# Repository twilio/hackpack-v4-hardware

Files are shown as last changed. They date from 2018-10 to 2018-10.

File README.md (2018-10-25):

# Hackpack v4 Hardware Collateral
This repo contains all of the hardware collateral you need to create a device functionally equivalent to the [Hackpack v4](https://hackpack.cc/) from [Twilio's SIGNAL 2018](https://signal.twilio.com/) Conference.

<p align="center">
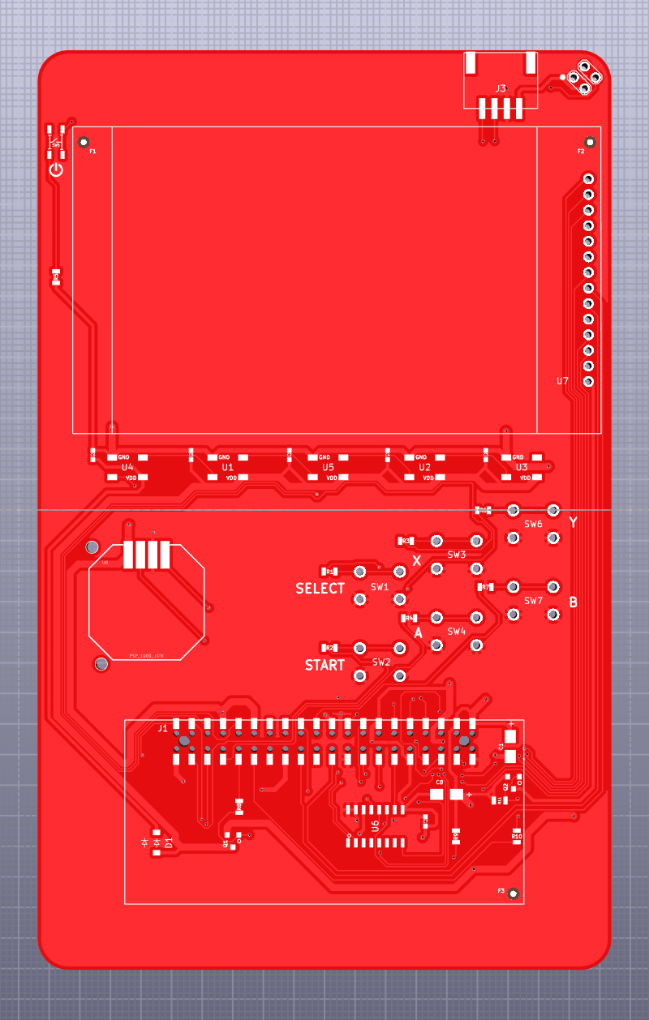
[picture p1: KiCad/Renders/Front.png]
Hackpack v4
  
</p>

See also our [blog post](https://www.twilio.com/blog/open-source-hardware-badge-hackpack-v4) announcing this repository.

## Hardware Collateral

Everything you need to build a badge PCB can be found in the `KiCad` folder. The Hackpack v4 was designed using KiCad major version 5. [Download a copy here](http://kicad-pcb.org/download/).

You'll also need to purchase a Raspberry Pi Zero W and a 8GB or larger MicroSD card to use the board.

### Don't want to use KiCad?

You can find pre-generated Gerbers in the `KiCad/Gerbers` directory. Use them at your PCB house of choice to manufacture a board.

We've also included the bill of materials and schematic in generic formats.

## Firmware

You can find firmware either [through our repository](https://github.com/twilio/hackpack-v4-firmware/) (start with a vanilla Raspbian installation) or pre-imaged on the [Hackpack v4](https://hackpack.cc/) site.

## Special Assembly Instructions

The Bill of Materials can be found in the `KiCad` directory. Some parts cannot be found at the normal supply sources and are best sourced from Amazon. 

The SMD Grove header was impossible to find in the US at the time this repo was released. Use a through hole Grove header and bend the pins with pliers for an excellent substitute.

The Amazon ILI9341 screen linked in the special assembly instructions has an inverted touchscreen to the one we used at the show. To fix the touchscreen driver you'll need to set flags:

```
echo "100" > /home/pi/.ili9341_touch.conf
sudo reboot
```

## License

Hardware collateral is licensed under [Solderpads 2.0](http://solderpad.org/licenses/SHL-2.0/), a hardware wrapper for the Apache 2.0 license. Please find a copy of both licenses in this repository.

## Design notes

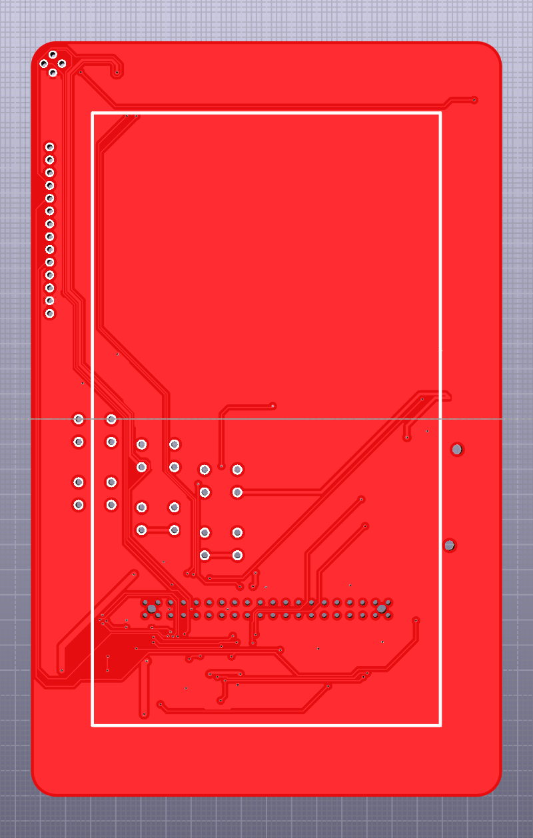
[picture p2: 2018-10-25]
KiCad/Renders/Back.png

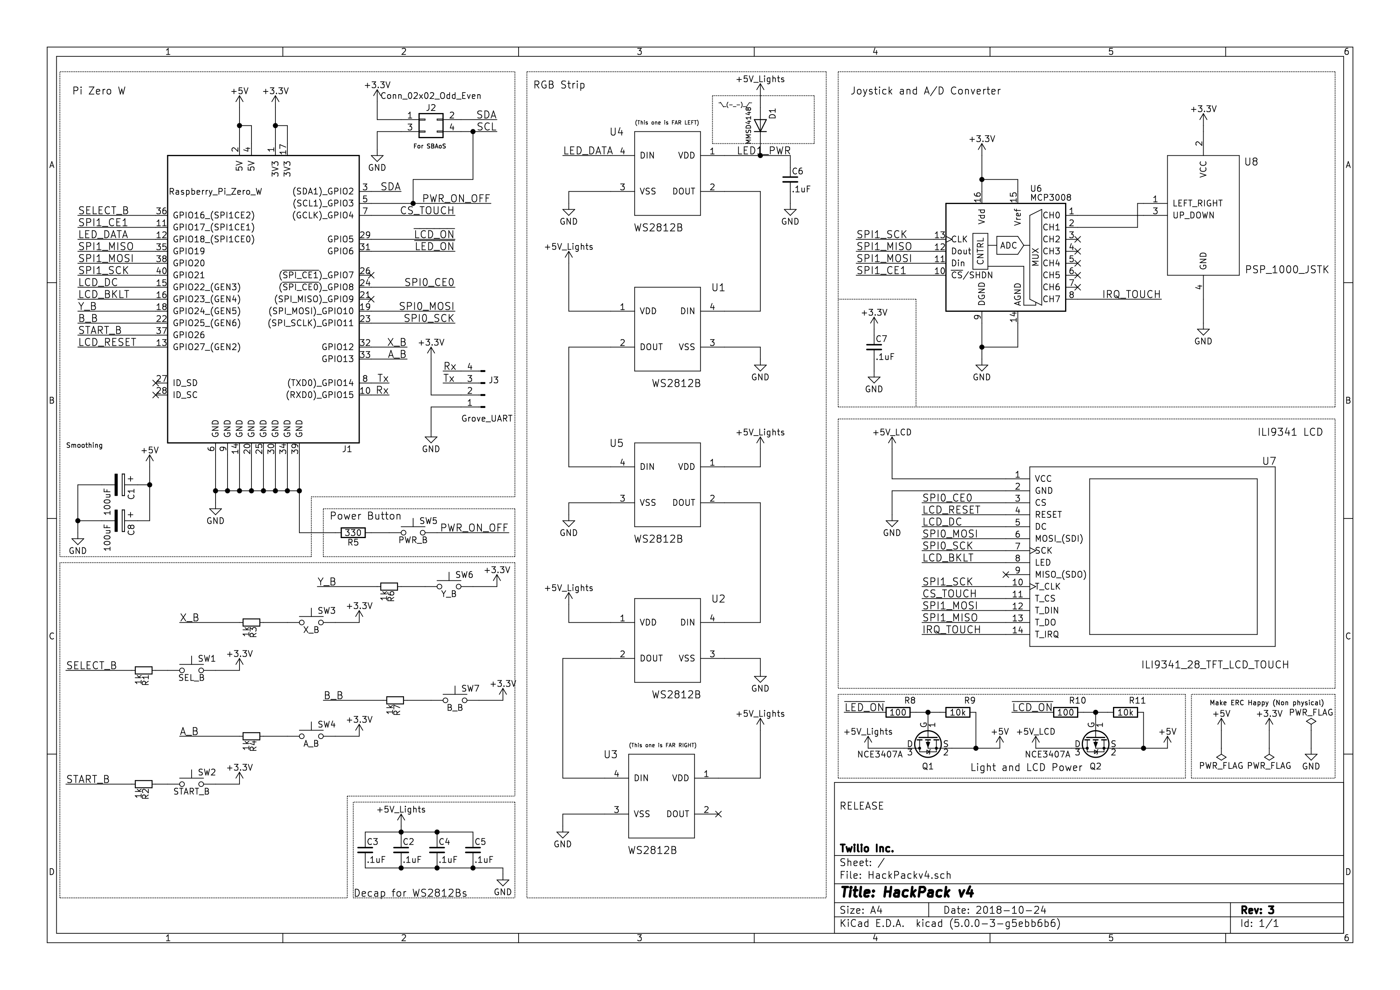
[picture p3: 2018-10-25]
KiCad/HackPackv4.sch.png

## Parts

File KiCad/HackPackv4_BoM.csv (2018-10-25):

Component | Description | Part | References | Value | Footprint | Quantity Per PCB | Datasheet | MFP | MFN | Characteristics | Can_Substitute | Notes | Package
1 | CAP CER 0.1UF 50V X7R 0603 | C_Small | C2 C3 C4 C5 C6 C7 | .1uF | C_0603 | 6 | https://www.mouser.com/datasheet/2/281/murata_03122018_GCM_Series-1310150.pdf | GCM188R71H104KA57D | MURATA | 0603 100nF-50V-10%-X7R | Y
2 | SMD CAP Tantalum 100uF-10V | CP | C1 C8 | 100uF | CP_Tantalum_Case-B_EIA-3528-21_Wave | 2 | https://www.mouser.com/datasheet/2/40/f93-776559.pdf | F931A107KBA | AVX | 100uF 10V 20% | Y | 2x for Smoothing 5V
3 | SMD Diode Switching 100V-200mA | D | D1 | MMSD4148 | D_SOD-123 | 1 | https://www.onsemi.com/pub/Collateral/MMSD4148T1-D.PDF | MMSD4148T3G | ON Semiconductor | MUST DROP >= .3 Forward Voltage!! SMD Diode Switching 100V-200mA | N | To drop voltage for the first LED to meet the 70% spec.
4 | NO NOT POPULATE | Conn_02x02_Odd_Even | J2 | Conn_02x02_Odd_Even | Pin_Header_Straight_2x02_Pitch2.54mm | 1 | NONE | DNP | DNP | NO NOT POPULATE | N | NO NOT POPULATE | NO NOT POPULATE
5 | Grove UART Header - Solder bent pins onto pads | Conn_01x04_Male | J3 | Grove_UART | Grove_Taifeng_1125R-SMT-4P | 1 | https://www.digikey.com/product-detail/en/seeed-technology-co-ltd/110990037/1597-1083-ND/5482561 | Buy on Digikey and Modify | -- |  | N | Bend pins & solder sideways
6 | Surface mount low profile header 40 pin 2 row | Raspberry_Pi_Zero_W | J1 | Raspberry_Pi_Zero_W | M20-7812045 | 1 | https://cdn.harwin.com/pdfs/M20-781.pdf | HLE-120-02-G-DV-A | Samtec | 40 Pin 2x20 2.54mm pitch SMD. | Y | WAIT ON SUBSTITUTE FROM ERIN & TWILIO
7 | MOSFET P-CH 30V 4.3A SOT23 | NCE3407A | Q1 Q2 | NCE3407A | SOT-23 | 2 | http://aosmd.com/res/data_sheets/AO3407A.pdf | AO3407A | Alpha & Omega Semiconductor | VGS th < -3, 10+V, 500mA+ | Y | Turn on LEDs, Screen
8 | SMD RES 100R-5%-1/8W | R | R8 R10 | 100 | R_0805 | 2 | http://www.yageo.com/documents/recent/PYu-RC_Group_51_RoHS_L_9.pdf | RC0805JR-07100RL | Yageo | 100R 5% 1/8W 0805 | Y | MOSFET Gate Input Protection
9 | SMD RES 10K-1%-1/8W;0805 | R | R9 R11 | 10k | R_0805 | 2 | http://www.yageo.com/documents/recent/PYu-RC_Group_51_RoHS_L_9.pdf | RC0805FR-0710KL | Yageo | 10K 1% or 5% 1/8W | Y | MOSFET Gate Pullup
10 | SMD RES 1K-5%-1/8W;0805 | R_Small | R1 R2 R3 R4 R6 R7 | 1k | R_0805 | 6 | http://www.yageo.com/documents/recent/PYu-RC_Group_51_RoHS_L_9.pdf | RC0805JR-071KL | Yageo | 1K 5% 1/8W | Y
11 | SMD RES 330R-1%-1/8W;0805 | R | R5 | 330 | R_0805 | 1 | http://www.yageo.com/documents/recent/PYu-RC_Group_51_RoHS_L_9.pdf | RC0805FR-07330RL | Yageo | 0805 5% or 1% 330R 1/8W | Y | Protection on button/pulldown
12 | DIP Button;SPST;160gf | SW_Push | SW4 | A_B | TS-1109_6.2mm_Push | 1 | https://www.ctscorp.com/wp-content/uploads/222A.pdf | 222ADVBA | CTS Electrocomponents |  | N | Used for SEL/START/A/B/X/Y Buttons
13 | DIP Button;SPST;160gf | SW_Push | SW7 | B_B | TS-1109_6.2mm_Push | 1 | https://www.ctscorp.com/wp-content/uploads/222A.pdf | 222ADVBA | CTS Electrocomponents |  | N | Used for SEL/START/A/B/X/Y Buttons
14 | SWITCH TACTILE SPST-NO 0.05A 12V | SW_Push | SW5 | PWR_B | ALPS_SKRPABE010 | 1 | https://www.e-switch.com/system/asset/product_line/data_sheet/218/TL3365.pdf | TL3365AF180QG | E-Switch | SMD 4.2mmx3mm 4 contact SPST Push | N | Power button
15 | DIP Button;SPST;160gf | SW_Push | SW1 | SEL_B | TS-1109_6.2mm_Push | 1 | https://www.ctscorp.com/wp-content/uploads/222A.pdf | 222ADVBA | CTS Electrocomponents |  | N | Used for SEL/START/A/B/X/Y Buttons
16 | DIP Button;SPST;160gf | SW_Push | SW2 | START_B | TS-1109_6.2mm_Push | 1 | https://www.ctscorp.com/wp-content/uploads/222A.pdf | 222ADVBA | CTS Electrocomponents |  | N | Used for SEL/START/A/B/X/Y Buttons
17 | DIP Button;SPST;160gf | SW_Push | SW3 | X_B | TS-1109_6.2mm_Push | 1 | https://www.ctscorp.com/wp-content/uploads/222A.pdf | 222ADVBA | CTS Electrocomponents |  | N | Used for SEL/START/A/B/X/Y Buttons
18 | DIP Button;SPST;160gf | SW_Push | SW6 | Y_B | TS-1109_6.2mm_Push | 1 | https://www.ctscorp.com/wp-content/uploads/222A.pdf | 222ADVBA | CTS Electrocomponents |  | N | Used for SEL/START/A/B/X/Y Buttons
19 | Screen & touch controller from Alibaba/Amazon | ILI9341_28_TFT_LCD_TOUCH | U7 | ILI9341_28_TFT_LCD_TOUCH | ILI9341_TFT_LCD | 1 | https://www.amazon.com/HiLetgo-240X320-Resolution-Display-ILI9341/dp/B073R7BH1B/ | Buy on Amazon | ILI9341 | ILI9341 Resistive Touchscreen 2.8" TFT LCD | N | Solder directly no header | CUSTOM
20 | DAC for Joystick and Touch | MCP3008 | U6 | MCP3008 | SOIC-16_3.9x9.9mm_Pitch1.27mm | 1 | https://www.mouser.com/datasheet/2/268/21295b-72710.pdf | MCP3008T-I/SL | Microchip Technology | Do not substitute | N | DAC
21 | PSP 1000 Joystick | PSP_1000_JSTK | U8 | PSP_1000_JSTK | JOYSTICK-PSP1000 | 1 | https://www.amazon.com/IDS-Joystick-Analog-Replacement-Black/dp/B073GYFP2M/ | Buy on Amazon | PSP1000_Joystick | Analog Resistive Joystick, Can Sub from Other Supplier of PSP 1000 Replacement Joystick | Y | Needs 2 screws | CUSTOM
22 | LED RGB 5050 SMD | WS2812B | U1 U2 U3 U4 U5 | WS2812B | LED_WS2812B-PLCC4 | 5 | http://www.inolux-corp.com/datasheet/SMDLED/Addressable%20LED/IN-PI554FCH.pdf | IN-PI554FCH | Inolux |  | N

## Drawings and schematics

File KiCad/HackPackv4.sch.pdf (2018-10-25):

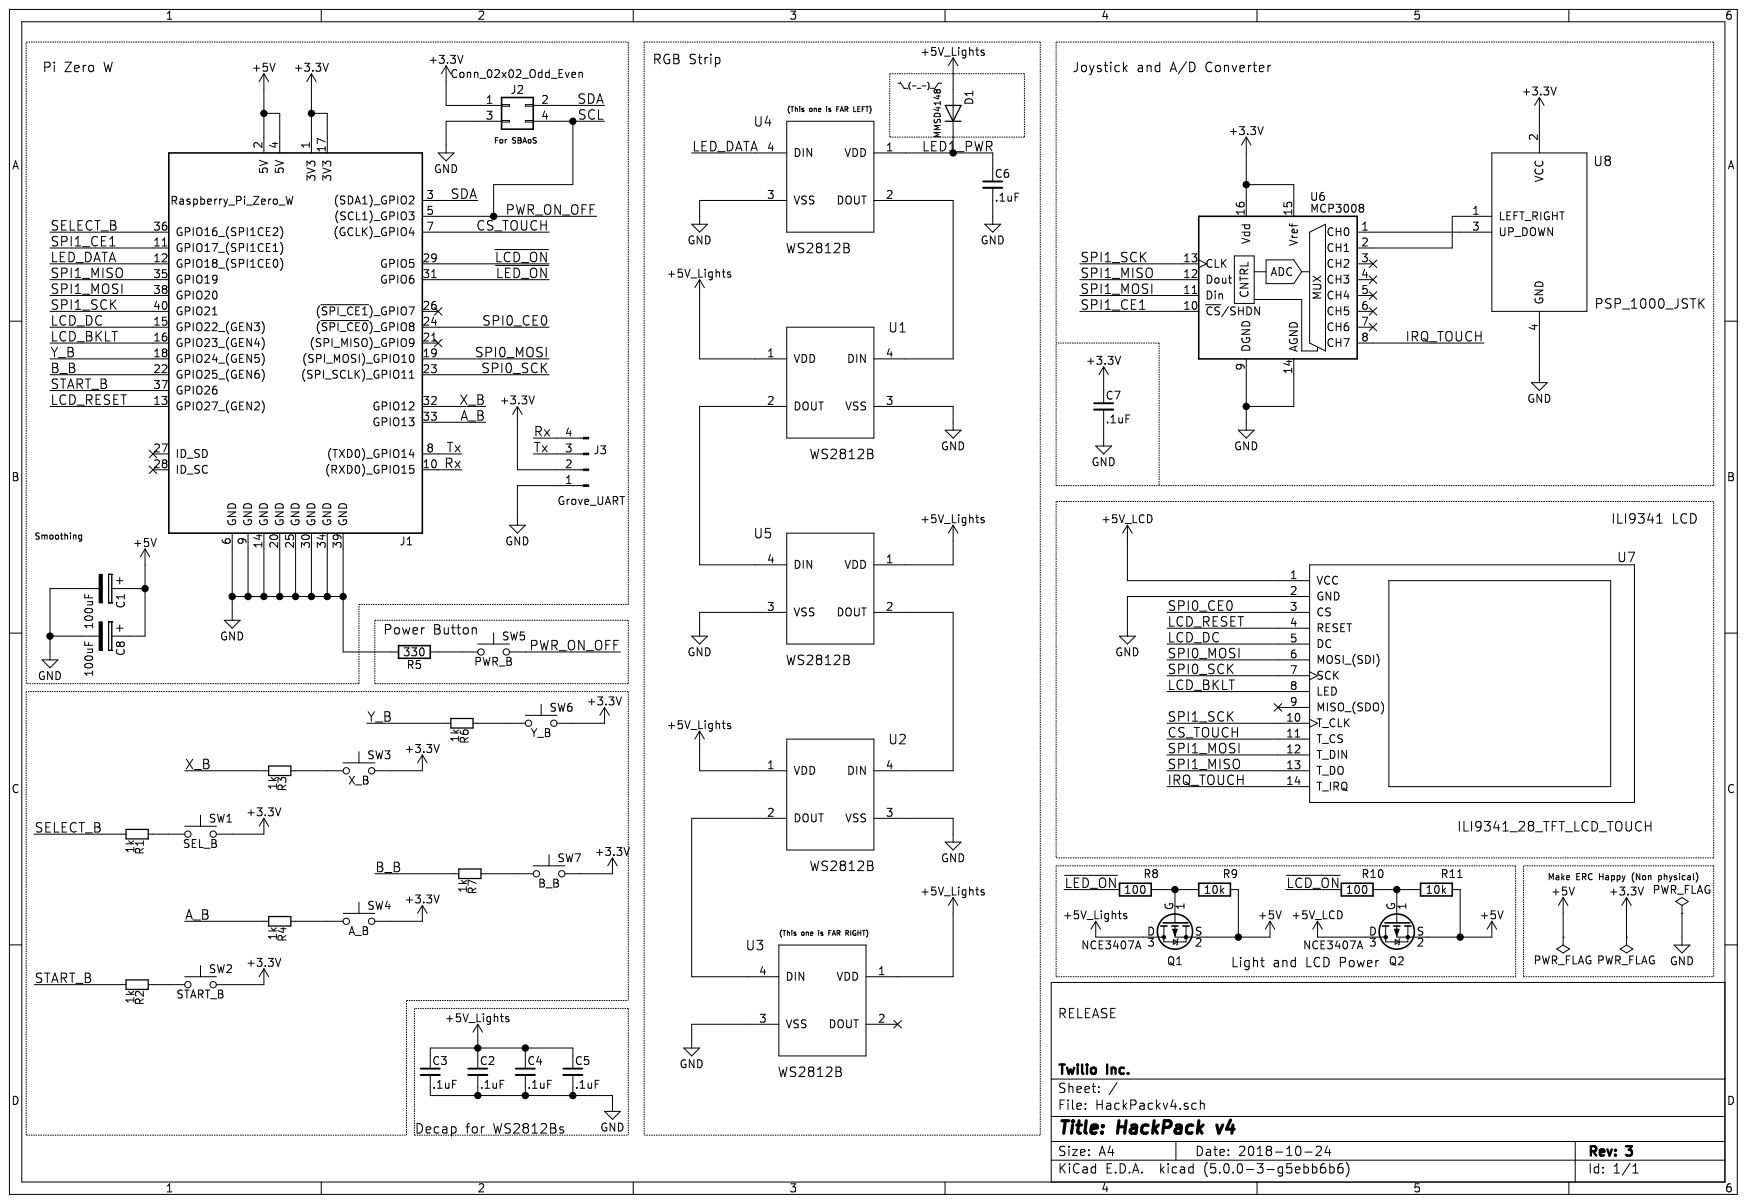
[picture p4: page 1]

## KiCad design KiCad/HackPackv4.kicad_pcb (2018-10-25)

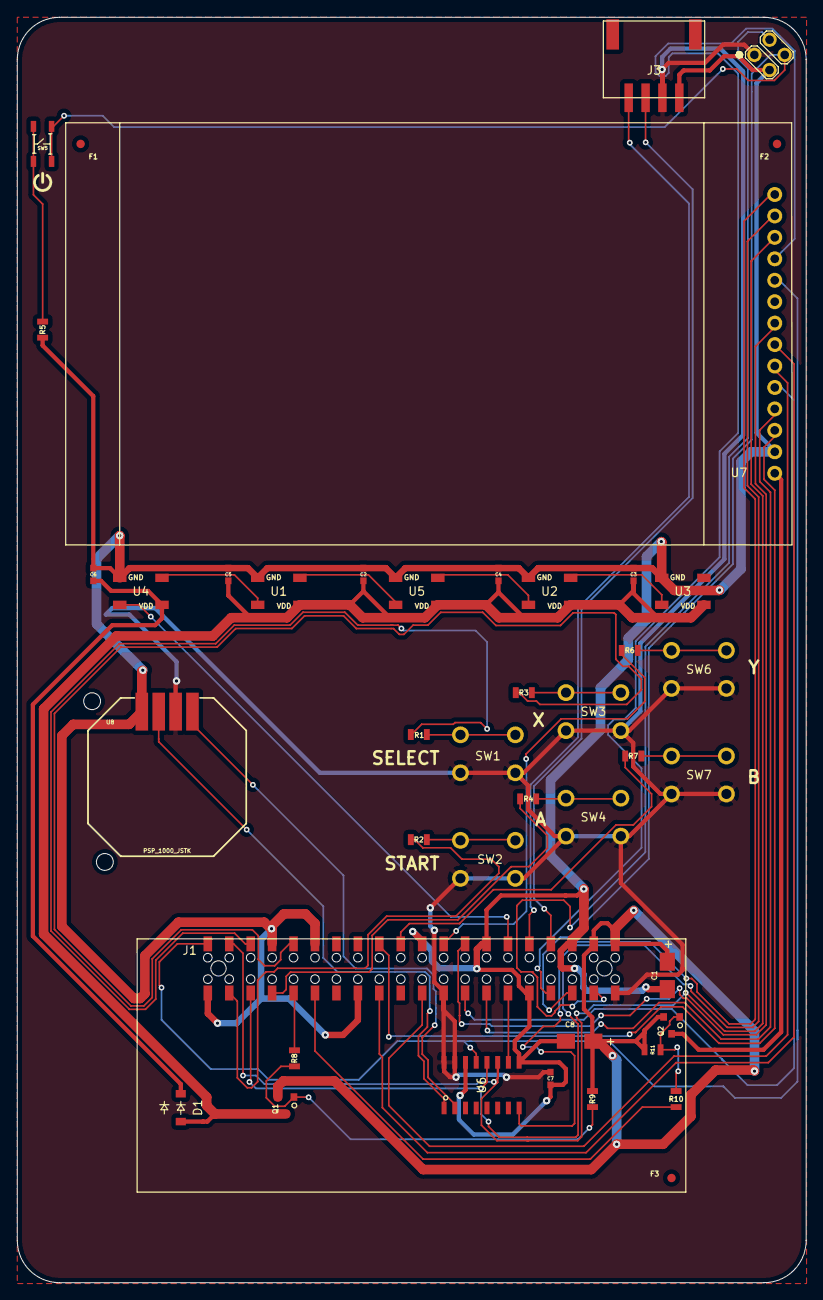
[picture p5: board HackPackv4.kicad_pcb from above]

Board: 2 copper layers, 93.5 x 149.9 mm, 43 parts (0 on the bottom side), 46 nets.

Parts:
C1, C8: 100uF; CP_Tantalum_Case-B_EIA-3528-21_Wave
C2, C3, C4, C5, C6, C7: .1uF; C_0603
D1: MMSD4148; D_SOD-123
F1, F2, F3: Fiducial_1mm_Dia_2mm_Outer
J1: Raspberry_Pi_Zero_W Header; M20-7812045
J2: Conn_02x02_Odd_Even; Pin_Header_Straight_2x02_Pitch2.54mm
J3: Grove_UART; Grove_Taifeng_1125R-SMT-4P
Q1, Q2: NCE3407A; SOT-23
R1, R2, R3, R4, R6, R7: 1k; R_0805
R5: 330; R_0805
R8, R10: 100; R_0805
R9, R11: 10k; R_0805
SW1: SEL_B; TS-1109_6.2mm_Push
SW2: START_B; TS-1109_6.2mm_Push
SW3: X_B; TS-1109_6.2mm_Push
SW4: A_B; TS-1109_6.2mm_Push
SW5: PWR_B; ALPS_SKRPABE010
SW6: Y_B; TS-1109_6.2mm_Push
SW7: B_B; TS-1109_6.2mm_Push
U1, U2, U3, U4, U5: WS2812B; LED_WS2812B-PLCC4
U6: MCP3008; SOIC-16_3.9x9.9mm_Pitch1.27mm
U7: ILI9341_28_TFT_LCD_TOUCH; ILI9341_TFT_LCD
U8: PSP_1000_JSTK; JOYSTICK-PSP1000

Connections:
+3V3: C7.1, J1.1, J1.17, J2.1, J3.2, SW1.2, SW2.2, SW3.2, SW4.2, SW6.2, SW7.2, U6.15, U6.16, U8.2
+5V: C1.1, C8.1, J1.2, J1.4, Q1.2, Q2.2, R9.1, R11.1
+5V_LCD: Q2.3, U7.1
+5V_LIGHTS: C2.1, C3.1, C4.1, C5.1, D1.2, Q1.3, U1.1, U2.1, U3.1, U5.1
/A_B: J1.33, R4.2
/B_B: J1.22, R7.2
/CS_TOUCH: J1.7, U7.11
/IRQ_TOUCH: U6.8, U7.14
/LCD_BKLT: J1.16, U7.8
/LCD_DC: J1.15, U7.5
/LCD_RESET: J1.13, U7.4
/LED1_PWR: C6.1, D1.1, U4.1
/LED_DATA: J1.12, U4.4
/PWR_ON_OFF: J1.5, J2.4, SW5.2
/Rx: J1.10, J3.4
/SDA: J1.3, J2.2
/SELECT_B: J1.36, R1.2
/SPI0_CE0: J1.24, U7.3
/SPI0_MOSI: J1.19, U7.6
/SPI0_SCK: J1.23, U7.7
/SPI1_CE1: J1.11, U6.10
/SPI1_MISO: J1.35, U6.12, U7.13
/SPI1_MOSI: J1.38, U6.11, U7.12
/SPI1_SCK: J1.40, U6.13, U7.10
/START_B: J1.37, R2.2
/Tx: J1.8, J3.3
/X_B: J1.32, R3.2
/Y_B: J1.18, R6.2
/~LCD_ON: J1.29, R10.2
/~LED_ON: J1.31, R8.2
GND: C1.2, C2.2, C3.2, C4.2, C5.2, C6.2, C7.2, C8.2, J1.6, J1.9, J1.14, J1.20, J1.25, J1.30, J1.34, J1.39, J2.3, J3.1, R5.2, U1.3, U2.3, U3.3, U4.3, U5.3, U6.9, U6.14, U7.2, U8.4
unnamed: Q1.1, R8.1, R9.2
unnamed: Q2.1, R10.1, R11.2
unnamed: R1.1, SW1.1
unnamed: R2.1, SW2.1
unnamed: R3.1, SW3.1
unnamed: R4.1, SW4.1
unnamed: R5.1, SW5.1
unnamed: R6.1, SW6.1
unnamed: R7.1, SW7.1
unnamed: U1.2, U5.4
unnamed: U1.4, U4.2
unnamed: U2.2, U3.4
unnamed: U2.4, U5.2
unnamed: U6.1, U8.3
unnamed: U6.2, U8.1

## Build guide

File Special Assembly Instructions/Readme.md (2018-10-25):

# Hackpack Special Assembly Instructions

1) J3, the Grove Header, is hard to find in the US. For protyotyping, we bent the pins of a TH part since it is the same pitch.
1) U7, the Touchscreen, should be soldered directly to the PCB. The bottom of the SD card should be flush to board (resting on it). It is not connected to the Raspberry Pi.
1) J1, the Raspberry Pi socket is sometimes hard to find depending on buys. Almost any 2.54mm pitch 40 pin 2 row header will work, but it's best to find a _low profile_ one that fits. (For example, HLE-120-02-G-DV-A from Samtec)
1) The joystick is... not great to work with. Here's the soldering method that worked for us:

    1) Insert 2 M2 screws from under the board through the holes
    1) Slide the joystick down the two screws
    1) Slightly lift the edge with the 4 metal pads away from PCB (fingernail width or so)
    1) Using an iron, flood solder on the exposed PCB pad under (tall enough it contacts the joystick pad above)
    1) I used .8mm solder reel
    1) If resistance between adjacent pads is between 3k and 7.5k or so, then I know it isn't shorting and it made contact with the joystick

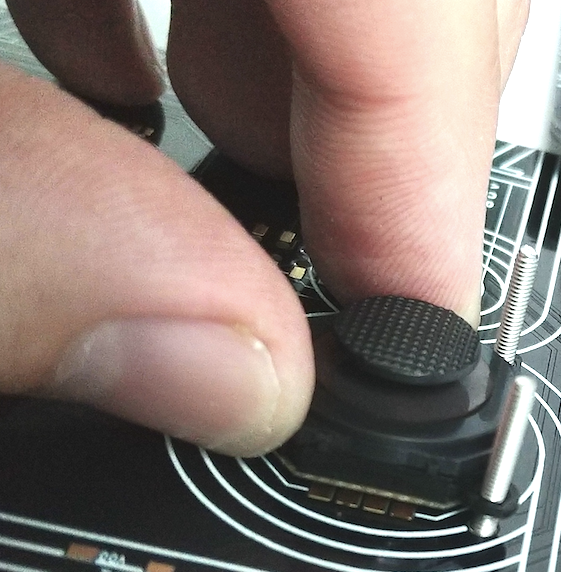
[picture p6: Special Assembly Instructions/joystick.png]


1) Here is a view of part orientation:

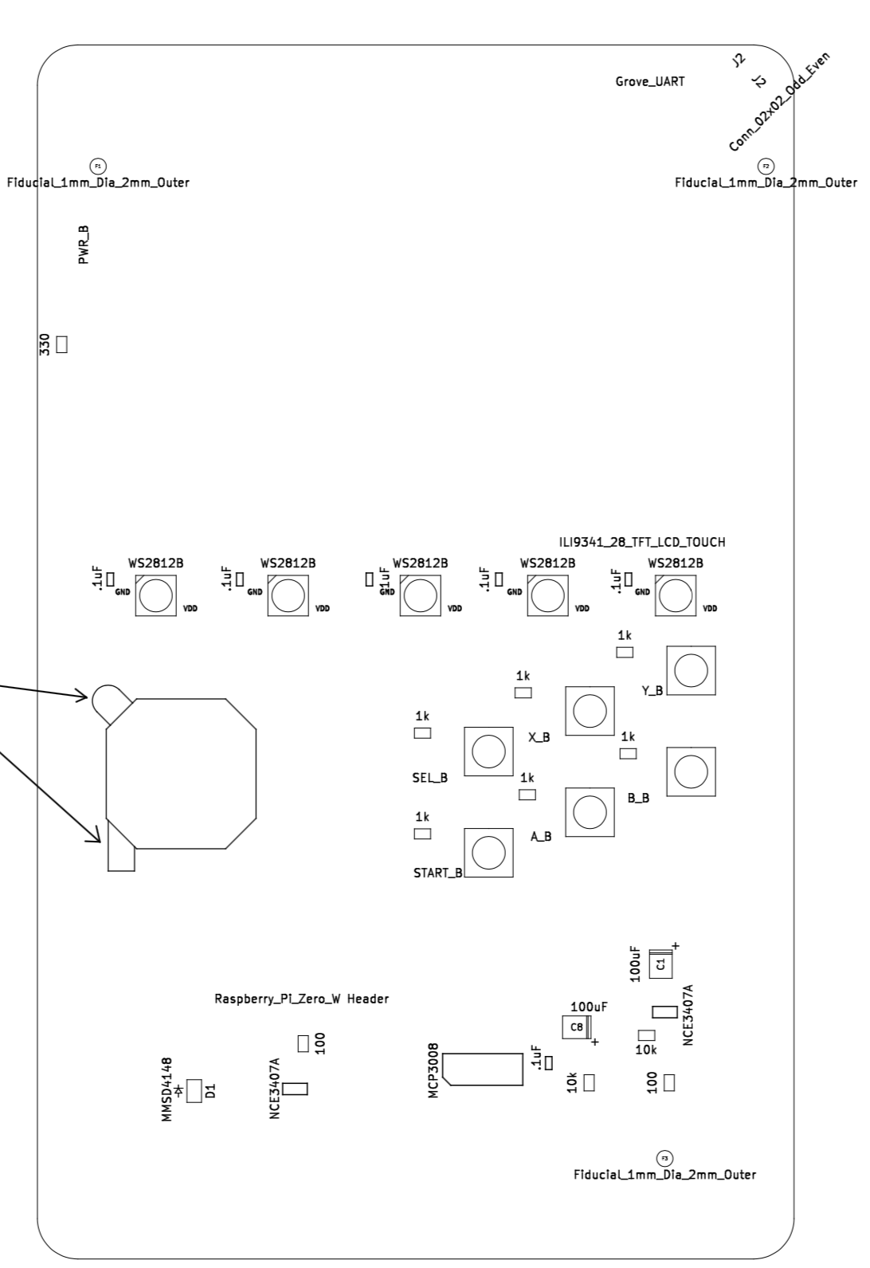
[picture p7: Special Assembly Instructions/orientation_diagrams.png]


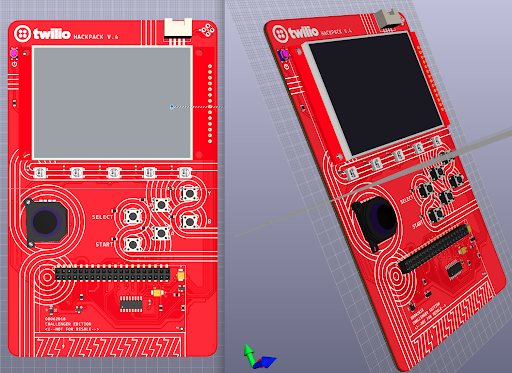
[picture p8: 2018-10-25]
KiCad/Renders/assembled_renders.png
